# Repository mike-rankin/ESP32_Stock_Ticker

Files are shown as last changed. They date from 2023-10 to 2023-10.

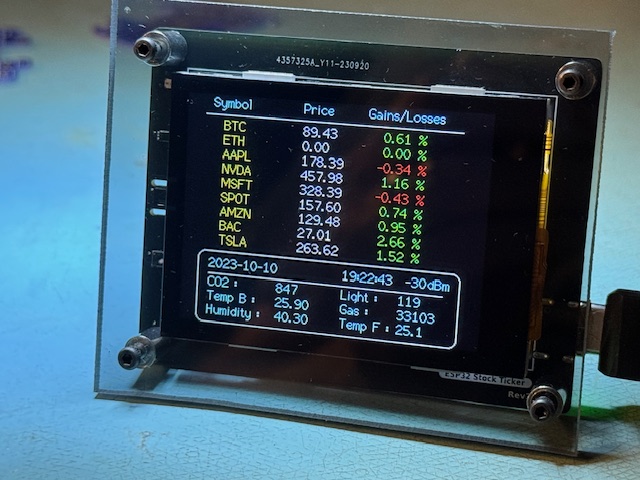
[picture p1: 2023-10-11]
Images/Image_0.jpg

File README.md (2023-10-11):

# ESP32_Stock_Ticker
ESP32 based multiple stocks ticker
This project was created to monitor multiple stock and crypto prices throughout the day without having check on my phone. I've seen a few versions on Kickstarter that monitor just one at a time and wanted more. The sketch uses a free Finnhub acount using a loop and Json to cycle though grabbing the data for each stock ticker. Becuase of the free account limitations, updating every five minutes or so is fine.

With plenty of room left over on the board I placed a few sensors that I had on hand. Some being used and some for future use. The QwiiC connector is free to connect other i2c sensors and the ambient light sensor could be used to auto adjust the lcd backlight. On the software side, you could grab the time and update the stock prices more often only when the market is open.


Top
Bottom

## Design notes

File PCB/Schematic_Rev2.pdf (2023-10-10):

# USB-CSHLD

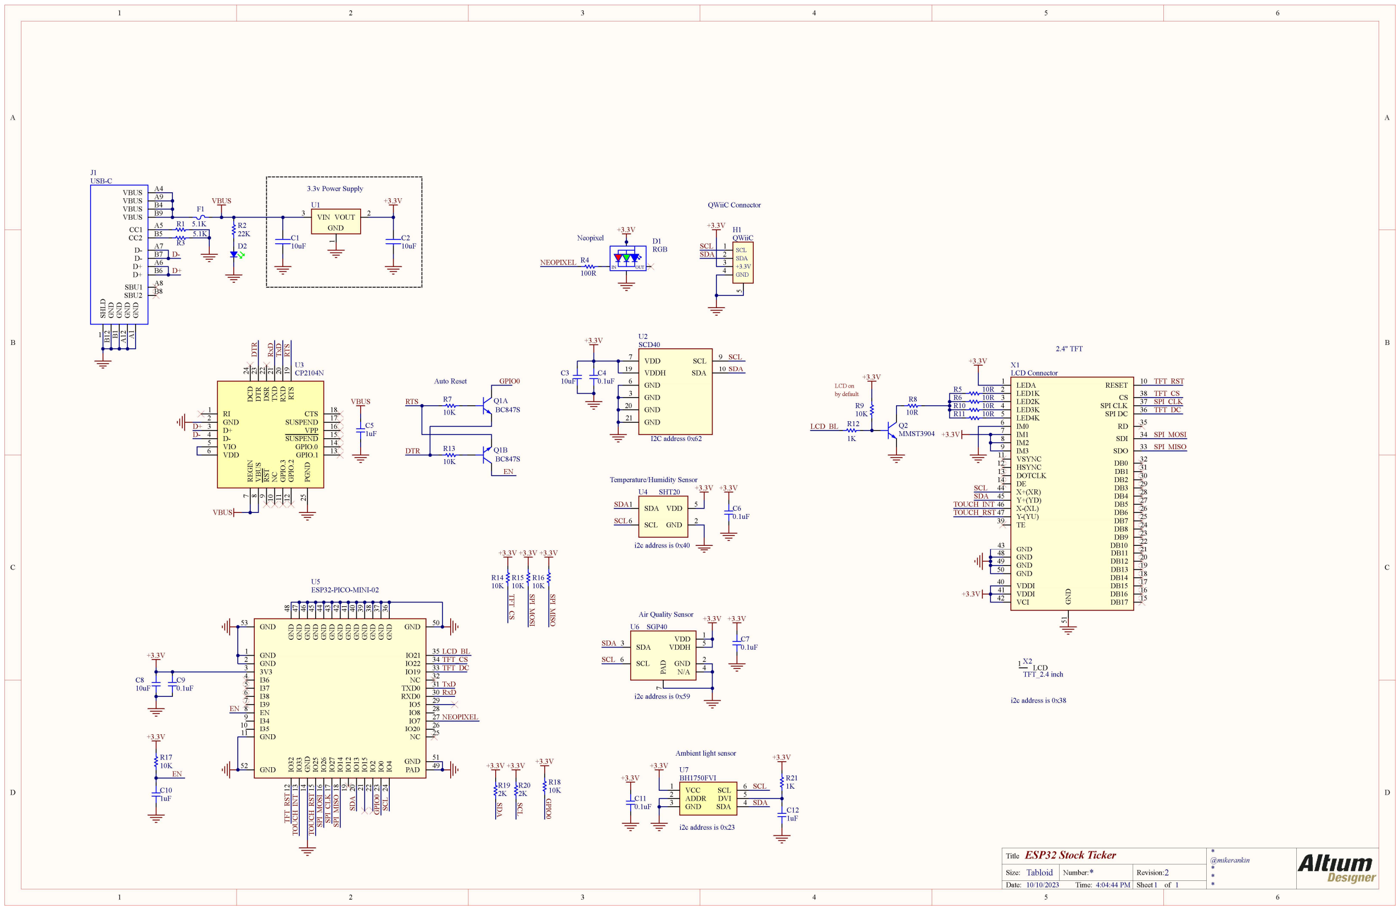
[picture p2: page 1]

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
@mikerankin
*
*
1 *

## ESP32 Stock Ticker

* | 2
10/10/2023 | 4:04:44 PM

Title

Size: | Number:
Date:

Revision:
Time: | Sheet | of

### Tabloid

LEDA 1
LED1K 2
LED2K 3
LED3K 4
LED4K 5
IM0 6
IM1 7
IM2 8
IM3 9
VSYNC 11
HSYNC 12
DOTCLK 13
DE 14
X+(XR) 44
Y+(YD) 45
X-(XL) 46
Y-(YU) 47
TE 39

GND 43
GND 48
GND 49
GND 50
VDDI 40
VDDI 41
VCI 42 | DB17 | 15 DB16 | 16 DB15 | 17 DB14 | 18 DB13 | 19 DB12 | 20 DB11 | 21 DB10 | 22 DB9 | 23 DB8 | 24 DB7 | 25 DB6 | 26 DB5 | 27 DB4 | 28 DB3 | 29 DB2 | 30 DB1 | 31 DB0 | 32
| SDO | | | | | | | | | | | | | | | | | | 33
| SDI | | | | | | | | | | | | | | | | | | 34
| RD | | | | | | | | | | | | | | | | | | 35
SPI DC | 36 SPI CLK | 37 CS | 38
RESET | 10 GND 51

X1
LCD Connector

LCD 1 X2
TFT_2.4 inch

TFT_CS

TFT_DC

SPI_MISO

+3.3V

2.4" TFT
+3.3V

+3.3V

R5 | 10R
R6 | 10R
R10 | 10R
R11 | 10R
LCD_BL
MMST3904

Q2

10R

R8

1K

R12

10K

R9

+3.3V
LCD on
by default

SCL
SDA
TOUCH_INT
TOUCH_RST

+3.3V

SCL

SDA

i2c address is 0x40

Temperature/Humidity Sensor SHT20
SDA 1

GND 2

SCL 6

VDD | 5
U4 | +3.3V

0.1uF

C6

SGP40

SDA 3

GND 2 PAD

7

N/A 4

SCL 6

VDD | 1
VDDH | 5

U6

SDA

SCL

+3.3V +3.3V

i2c address is 0x59

Air Quality Sensor

0.1uF

C7

3.3v Power Supply

22K

R2

D-

D+ GND A¹ GND B¹²

VBUS | A4
SBU2 | B8
VBUS | B9

1

CC1 | A5
D- | B7
D+ | A6
D- | A7
D+ | B6
SBU1 | A8
CC2 | B5
VBUS | B4 VBUS | A9 GND B¹ GND A¹²

J1

D2

R1 5.1K
5.1K
R3

+3.3V 1
VIN 3 | VOUT | 2

GND

U1

10uF

C2
10uF

C1

F1

1
2
3
4

QWiiC

GND

+3.3V

SDA

## SCL5

H1 +3.3V

SCL
SDA

QWiiC Connector

NEOPIXEL

NEOPIXEL

Neopixel

100R

R4
IN | OUT

D1
RGB

+3.3V

SPI_CLK

SPI_MOSI

TFT_RST

+3.3V

LCD_BL

10K

R18 SDA SCL

+3.3V +3.3V

2K

R19
2K

R20

+3.3V

+3.3V

EN

10K

R17

0.1uF

C9

TFT_CS
TFT_DC

1uF

C10

ESP32-PICO-MINI-02

GND 1

GND 51

GND 2
3V3 3
I36 4
I37 5
I38 6
I39 7
EN 8
I34 9
I35 10
GND 11 | IO³² 12 IO³³ 13 GND 14 IO²⁵ 15 IO²⁶ 16 IO²⁷ 17 IO¹⁴ 18 IO¹² 19 IO¹³ 20 IO¹⁵ 21 IO² 22 IO⁰ 23
NC | 25 IO20 | 26 IO7 | 27 IO8 | 28 IO5 | 29 RXD0 | 30 TXD0 | 31 NC | 32 IO19 | 33 IO22 | 34 IO21 | 35 GND ³⁶ GND ³⁷ GND ³⁸ GND ³⁹ GND ⁴⁰ GND ⁴¹ GND ⁴² GND ⁴³ GND ⁴⁴ GND ⁴⁵ GND ⁴⁶ GND ⁴⁷ | IO⁴ 24 GND ⁴⁸

GND 52

GND 53 | GND | 50
PAD | 49

U5

EN

RxD

TxD | GPIO0
10uF
C8 | TOUCH_INT | TOUCH_RST TFT_RST | SPI_MOSI SPI_CLK SPI_MISO | SDA | GPIO⁰ SCL

D-

D+ | DTR | RTS DCD ²⁴ | CP2104N

RI 1
GND 2
D+ 3
D- 4
VDD 6 | REGIN

### 7 VBUS

### 8 RST

### 9 NC 10

SUSPEND | 15
SUSPEND | 17 GPIO.3 11 GPIO.2 12

VIO 5

GPIO.1 | 13 GPIO.0 | 14
VPP | | 16
CTS | 18 RTS ¹⁹ RXD ²⁰ TXD ²¹ DSR ²² DTR ²³ | PGND 25

U3

1uF

C5

VBUS

# VBUS RxD TxD

DTR

RTS
BC847S

Q1A

Q1B
BC847S
EN
Auto Reset | GPIO0

10K

R7

10K

R13

VBUS

10K

R14
10K

R15
10K
R16 TFT_CS | SPI_MOSI | SPI_MISO

+3.3V +3.3V +3.3V

+3.3V | SCD40

VDD 7
VDDH 19
GND 6
GND 3
SDA | 10
SCL | 9

GND 20
GND 21

U2

SCL
SDA

I2C address 0x62

0.1uF

C4
10uF

C3

BH1750FVI
VCC 1
ADDR 2
GND 3
SDA | 4
DVI | 5
SCL | 6

U7
+3.3V

+3.3V

1K

R21
SCL

SDA

+3.3V

i2c address is 0x23

Ambient light sensor

0.1uF

C11

1uF

C12

i2c address is 0x38

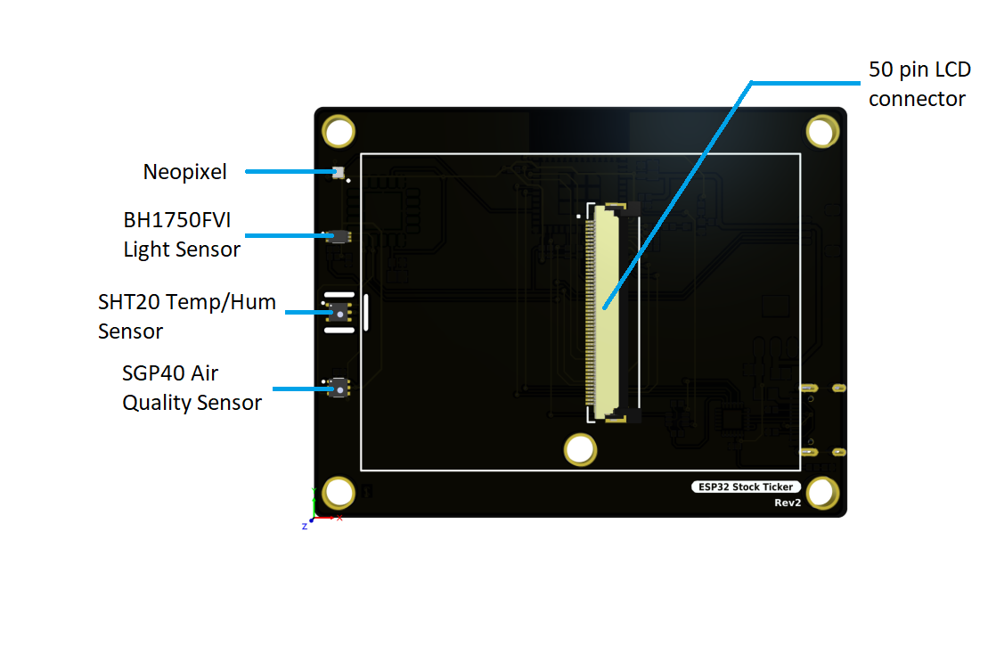
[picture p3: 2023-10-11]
Images/Top.png

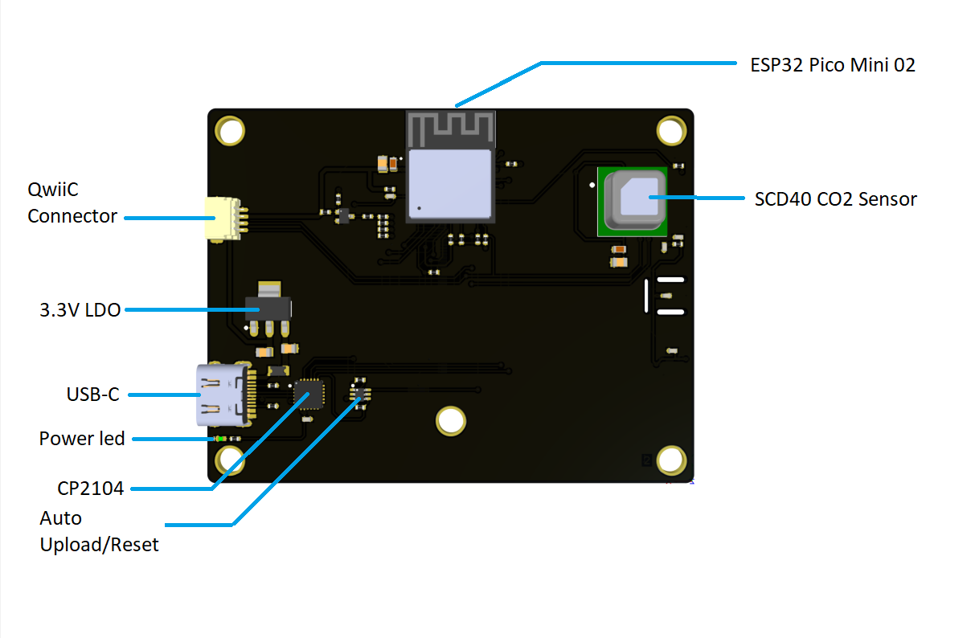
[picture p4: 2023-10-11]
Images/Bottom.png

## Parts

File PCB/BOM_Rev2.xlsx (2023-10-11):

Designator | Quantity | Description | Value | Part_Number | Manufacturer | Vendor
C1, C2, C3, C8 | 4 | CAP 10uF 16V 0805 | 10uF
C4, C9 | 2 | CAP 0.1uF 0603 | 0.1uF
C5, C10, C12 | 3 | CAP 1uF 0402 | 1uF
C6, C7, C11 | 3 | CAP 0.1uF 0402 | 0.1uF
D1 | 1 | NEOPIXEL | NeoPixel | C2909055 | OPSCO | LCSC
D2 | 1 | LED Green 0402 | Green Led | C74338 |  | LCSC
F1 | 1 | PTC FUSE 500mA hold, 1A trip 0805 SMD | TLC-PSMD050 | TLC-PSMD050 | TLC | LCSC
H1 | 1 | CONN HEADER 4POS .100 R/A QWIIC | QWiiC | PRT-16766 | Sparkfun | Digi-Key
J1 | 1 | CONN RECPT USB-C | USB-C | C165948 | KHE | LCSC
Q1 | 1 | TRANS 2NPN 44V 0.1A SC-70-6 | 2NPN | BC847S | Changjiang | LCSC
Q2 | 1 | TRANSISTOR NPN GP 40V SC-70 | MMST3904 | C54879 | Changjiang | LCSC
R1, R3 | 2 | RES 5.1K 0402 | 5.1K
R2 | 1 | RES 22K 0402 | 22K
R4 | 1 | RES 100R 0402 | 100R
R5, R6, R8, R10, R11 | 5 | RES 10R 0402 | 10R
R7, R9, R13, R14, R15, R16, R17, R18 | 8 | RES 10K 0402 | 10K
R12, R21 | 2 | RES 1K 0402 | 1K
R19, R20 | 2 | RES 2K 0402 | 2K
U1 | 1 | IC REG LDO 3.3V 1A SOT223-3 | 3.3V 1A LDO | NCP1117LPST33T3G | ON Semi | LCSC
U2 | 1 | CO2 SENSOR 50 PPM I2C SMD | SCD40 | SCD40 | Sensirion
U3 | 1 | IC BRIDGE USB TO UART 24QFN | CP2104N | C47742 | Silicon Labs | LCSC
U4 | 1 | SENSOR HUMID/TEMP 3V I2C 3% SMD | SHT20 | SHT20 | Sensirion AG | Digi-Key
U5 | 1 | WIFI/Bluetooth, Mini Module | ESP32-PICO-MINI-02 |  | Espressif
U6 | 1 | AIR QUALITY GAS SENSOR FOR VOC'S | SGP40 | SGP40-D-R4 | Sensirion AG | Digi-Key
U7 | 1 | Optical Sensor Ambient I2C 6-SMD | BH1750FVI | C78960 | Rohm | LCSC
X1 | 1 | FFC, FPC 50 pin 0.5mm Connector for 2.4" TFT | LCD Connector | C397332 | XKB | LCSC
X2 | 1 | 2.4 INCH TFT GLASS COLOR |  | ER-TFT024-3 | BuyDisplay.com | BuyDisplay

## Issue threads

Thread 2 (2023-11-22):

Port to other ESP32 display?

dkim777, 2023-11-22:
Looks like your unit is from Adafruit?

I have a cheap ESP32 display
https://github.com/witnessmenow/ESP32-Cheap-Yellow-Display

it supports TFT_eSPI
Do you think it's easy to port?

mike-rankin, 2023-11-22:
Nice! I’ve seen several posts about the big yellow display. Porting will be easy but you can just comment out the sensor stuff. The code is pretty simple just grabbing data and sorting.

anthonyjclarke, 2023-11-22:
And a good community of support around the Cheap Yellow Display (CYD) here - https://discord.gg/H5RnbZBD

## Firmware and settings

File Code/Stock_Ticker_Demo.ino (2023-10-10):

//Stock ticker demo sketch

#include <TFT_eSPI.h> 
#include <WiFiUdp.h> 
#include <HTTPClient.h>
#include <ArduinoJson.h> 
#include "Splash.h"
#include <NTPClient.h>
#include <WiFiUdp.h>
#include <HTTPClient.h>  
#include "Wifi_Icons.h"

#include <SensirionI2CScd4x.h>
#include <BH1750.h>
#include "Adafruit_SGP40.h"
#include <Adafruit_NeoPixel.h>
#include "DFRobot_SHT20.h"

TFT_eSPI tft = TFT_eSPI(); 
SensirionI2CScd4x scd4x;
BH1750 lightMeter;
Adafruit_SGP40 sgp;
Adafruit_NeoPixel pixels(1, 7, NEO_GRB + NEO_KHZ800);
DFRobot_SHT20 sht20(&Wire, SHT20_I2C_ADDR);

WiFiUDP ntpUDP;
NTPClient timeClient(ntpUDP, "pool.ntp.org");
String months[12]={"January", "February", "March", "April", "May", "June", "July", "August", "September", "October", "November", "December"};

uint32_t targetTime = 0;      
const long interval = 60000;  //Update every minute

const char* ssid     = "SSID";      
const char* password = "PASSWORD";         

#define LCD_BACKLIGHT 21

#define TFT_LIGHTGREY 0xD69A
#define TFT_DARKGREY  0x4208 
#define TFT_GREEN     0x07E0
#define TFT_LightBlue 0x867D
#define TFT_Orange    0xFDA0
#define TFT_SILVER    0xC618 
#define TFT_PURPLE    0x780F 

String payload="";
double current=0;

unsigned long previousTime = 0;
const unsigned long eventInterval=300000;     //300000 is 5 minutes
//const unsigned long eventInterval=600000;   //600000 is 10 minutes

StaticJsonDocument<6000> doc;

//int deb=0;
//int brightnes[5]={40,80,120,160,200};
//int b=1;

void setup() 
{
  Serial.begin(115200);
  tft.init();
  Wire.begin(13,4);  //Pico mini
  tft.setRotation(1);
  tft.setSwapBytes(true);
  tft.fillScreen(TFT_BLACK);
  pinMode(LCD_BACKLIGHT, OUTPUT);
  connect_to_wifi();

  uint16_t error;
  char errorMessage[256];
  scd4x.begin(Wire);
  sgp.begin();
  sht20.initSHT20();
  pixels.begin();
  lightMeter.begin(); 

  reset_screen();
  tft.pushImage(0,0,320,240,Splash);
  delay(3000);
  reset_screen();

  main_page();
  stock_page("BTC","ETH","AAPL","NVDA","MSFT","SPOT","AMZN","BAC","TSLA");     //Edit your preferred stocks here

  timeClient.begin();
  timeClient.setTimeOffset(-10800);  //My timezone

  error = scd4x.stopPeriodicMeasurement();
  if (error) 
  {
   Serial.print("Error trying to execute stopPeriodicMeasurement(): ");
  }

  //Start Measurement
  error = scd4x.startPeriodicMeasurement();
  if (error) 
  {
   Serial.print("Error trying to execute startPeriodicMeasurement(): ");
   errorToString(error, errorMessage, 256);
   Serial.println(errorMessage);
  }

  Serial.println("Waiting for first measurement... (5 sec)");
  blink_led();
}

void loop() 
{
 unsigned long currentTime = millis(); 
 timeClient.update();

 time_t epochTime = timeClient.getEpochTime();
 struct tm *ptm = gmtime ((time_t *)&epochTime);   //Get a time structure

 int monthDay = ptm->tm_mday;
 int currentMonth = ptm->tm_mon+1;
 String currentMonthName = months[currentMonth-1];
 int currentYear = ptm->tm_year+1900;
 String currentDate = String(currentYear) + "-" + String(currentMonth) + "-" + String(monthDay);

 tft.drawLine( 30, 187, 280, 187, TFT_WHITE);     

 tft.setTextColor(TFT_LightBlue,TFT_BLACK);
 tft.drawString(String(currentDate),30,168,2);
 tft.drawString(String(timeClient.getFormattedTime()),175,168,2);

 digitalWrite(LCD_BACKLIGHT, HIGH);
 Serial.println("Waiting...");
 delay(100);
 main_page();
 read_co2();
 read_light();
 read_gas();
 read_front_temp();
 show_RSSI();

 if (currentTime - previousTime >= eventInterval) 
 {
  Serial.println("Refresh Data");
  reset_screen();
  stock_page("BTC","ETH","AAPL","NVDA","MSFT","SPOT","AMZN","BAC","TSLA");  //Edit your stock names here
  previousTime = currentTime;
  timeClient.update();
 }
}


void connect_to_wifi()
{
 WiFi.begin(ssid, password);
 tft.setTextColor(TFT_GREEN,TFT_BLACK); 
 tft.setTextSize(2); 
 tft.setCursor (45,100); 
 tft.print("Connecting to Wifi");
 delay(2000);

 while (WiFi.status() != WL_CONNECTED)
 {
  delay(150);
  tft.print(".");
  delay(150);
 }
 tft.fillScreen(TFT_BLACK);
 tft.setTextSize(2); 
 tft.setCursor (90,100);  
 tft.print("Connected");
 tft.setCursor (95,130); 
 tft.print("IP address: ");
 tft.setCursor (90,160); 
 tft.print(WiFi.localIP());
 delay(4000);
 tft.fillScreen(TFT_BLACK);
}

void show_RSSI()
{
 tft.drawString(String(WiFi.RSSI()),242,168,2);
 tft.drawString("dBm",265,168,2);   
}


void read_light()
{
 int lux = lightMeter.readLightLevel();
 tft.setTextSize(1);  
 tft.setTextColor(TFT_LightBlue,TFT_BLACK);
 tft.drawString("Light : ",175,188,2);   
 tft.drawString(String(lux),235,188,2);
}

void read_gas()
{
 uint16_t raw;
 raw = sgp.measureRaw();
 tft.setTextSize(1);  
 tft.setTextColor(TFT_LightBlue,TFT_BLACK);
 tft.drawString("Gas : ",175,203,2);
 tft.drawString(String(raw),235,203,2);
}

void read_front_temp()
{
 float temp = sht20.readTemperature();
 tft.setTextSize(1);  
 tft.setTextColor(TFT_LightBlue,TFT_BLACK);
 tft.drawString("Temp F : ",175,218,2);
 tft.drawString(String(temp,1),235,218,2);
}


void read_co2()
{
  uint16_t error;
  char errorMessage[256];

  delay(100);

  // Read Measurement
  uint16_t co2 = 0;
  float temperature = 0.0f;
  float humidity = 0.0f;
  bool isDataReady = false;
  error = scd4x.getDataReadyFlag(isDataReady);
  if (error) 
  {
    Serial.print("Error trying to execute getDataReadyFlag(): ");
    errorToString(error, errorMessage, 256);
    Serial.println(errorMessage);
    return;
  }
  if (!isDataReady) 
  {
    return;
  }
  error = scd4x.readMeasurement(co2, temperature, humidity);
  if (error)
  {
    Serial.print("Error trying to execute readMeasurement(): ");
    errorToString(error, errorMessage, 256);
    Serial.println(errorMessage);
  } else if (co2 == 0)
   {
    Serial.println("Invalid sample detected, skipping.");
   } else 
   {
    Serial.print("Co2:");
    Serial.print(co2);
    Serial.print("\t");
    Serial.print("Temperature:");
    Serial.print(temperature);
    Serial.print("\t");
    Serial.print("Humidity:");
    Serial.println(humidity);

    tft.setTextSize(1);  
    tft.setTextColor(TFT_LightBlue,TFT_BLACK);
    tft.drawString("CO2 : ",30,188,2);     
    tft.drawString(String(co2),105,188,2);
    tft.drawString("Temp B : ",30,203,2);
    tft.drawString(String(temperature),105,203,2);
    tft.drawString("Humidity : ",30,218,2);      
    tft.drawString(String(humidity),105,218,2);  
  }
}



 void main_page()
 {
  tft.setTextSize(1);  
  tft.setTextColor(TFT_LightBlue,TFT_BLACK);
  tft.drawString("Symbol",28,0,2);  
  tft.drawString("Price",125,0,2); 
  tft.drawString("Gains/Losses",193,0,2);

  tft.drawLine( 20, 20, 290, 20, TFT_WHITE);     
  tft.drawRoundRect(18, 163, 280, 77, 6, TFT_WHITE);      
}
  
void reset_screen()
{
 tft.fillScreen(TFT_BLACK);
} 

void stock_page(String s1,String s2,String s3,String s4,String s5,String s6,String s7,String s8,String s9)
{
 read_price(40,23,s1);   
 read_price(40,38,s2);  
 read_price(40,53,s3);
 read_price(40,68,s4);
 read_price(40,83,s5);
 read_price(40,98,s6);
 read_price(40,113,s7);
 read_price(40,128,s8);
 read_price(40,143,s9); 
} 

void read_price(int x_i,int y_i,String stock_name)
{ 
 float currentPrice;
 float differenceInPrice; 
 float percentchange; 
 
 HTTPClient http; 
 http.begin("https://finnhub.io/api/v1/quote?symbol="+stock_name+"&token=YOUR-TOKEN-HERE");   //Edit your key here
    
 int httpCode = http.GET();  
 if (httpCode > 0)
 { 
  payload = http.getString();
  char inp[payload.length()];
  payload.toCharArray(inp,payload.length());
  deserializeJson(doc,inp);

  //c = Current price, d = Change, dp = Percent change, pc = Previous close price
  String v=doc["c"];    
  String c=doc["dp"];  
  current=v.toDouble(); 
  percentchange=c.toDouble();
  
  tft.setTextSize(1);
  tft.setTextColor(TFT_Orange,TFT_BLACK);
  tft.drawString(stock_name,x_i,y_i,2);  
  tft.setTextColor(TFT_LIGHTGREY,TFT_BLACK);                       
  tft.drawString(" ",50+x_i,y_i,2);                     
  tft.drawString(String(current),85+x_i,y_i,2);         
  
  if(percentchange<0.0)
  {
   tft.setTextColor(TFT_RED);
   tft.drawString(" ",130+x_i,y_i,2);                     
   tft.drawString(String(percentchange),165+x_i,y_i,2);   
   tft.drawString("  %",195+x_i,y_i,2);                   
  } 
  
  else
  {
   tft.setTextColor(TFT_GREEN);
   tft.drawString(" ",130+x_i,y_i,2);                      
   tft.drawString(String(percentchange),170+x_i,y_i,2);  
   tft.drawString(" %",200+x_i,y_i,2);                   
  }
 }
}

void blink_led()
{
 pixels.clear(); 

 pixels.setPixelColor(0, pixels.Color(25, 0, 0));
 pixels.show();  
 delay(100); 
 pixels.clear();
  
 pixels.setPixelColor(0, pixels.Color(0, 25, 0));
 pixels.show();  
 delay(100);
 pixels.clear();

 pixels.setPixelColor(0, pixels.Color(0, 0, 25));
 pixels.show();  
 delay(100); 
 pixels.clear(); 

 pixels.setPixelColor(0, pixels.Color(0, 0, 0));
 pixels.show();  
 delay(100); 
}


  

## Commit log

2023-10-10 Added schematic
2023-10-10 Added pcb files
    [BOM_Rev2.xlsx, PCB_Project.PrjPcb, Schematic_Rev2.SchDoc]
2023-10-11 Updated files
    [BOM_Rev2.xlsx]
